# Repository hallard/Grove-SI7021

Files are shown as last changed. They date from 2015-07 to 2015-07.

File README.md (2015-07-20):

Grove SI7021 Temperature and Humidity Sensor
============================================

Boards made for testing and validate Ultra Low Power node boards you can connect grove connector to make it original "grove" or header pin to make it for breadboarding.

- The SI7021 pads have been resized to be easily hand soldered with an iron soldering.
- You can enable/disable the pullup with a solder pad.
- This board as no regulator on board, should be used only with 3.3V devices or add a level shifter.

##Detailed Description

Everything about ULPNode used with this board is located [here][1] on my blog

##Schematics
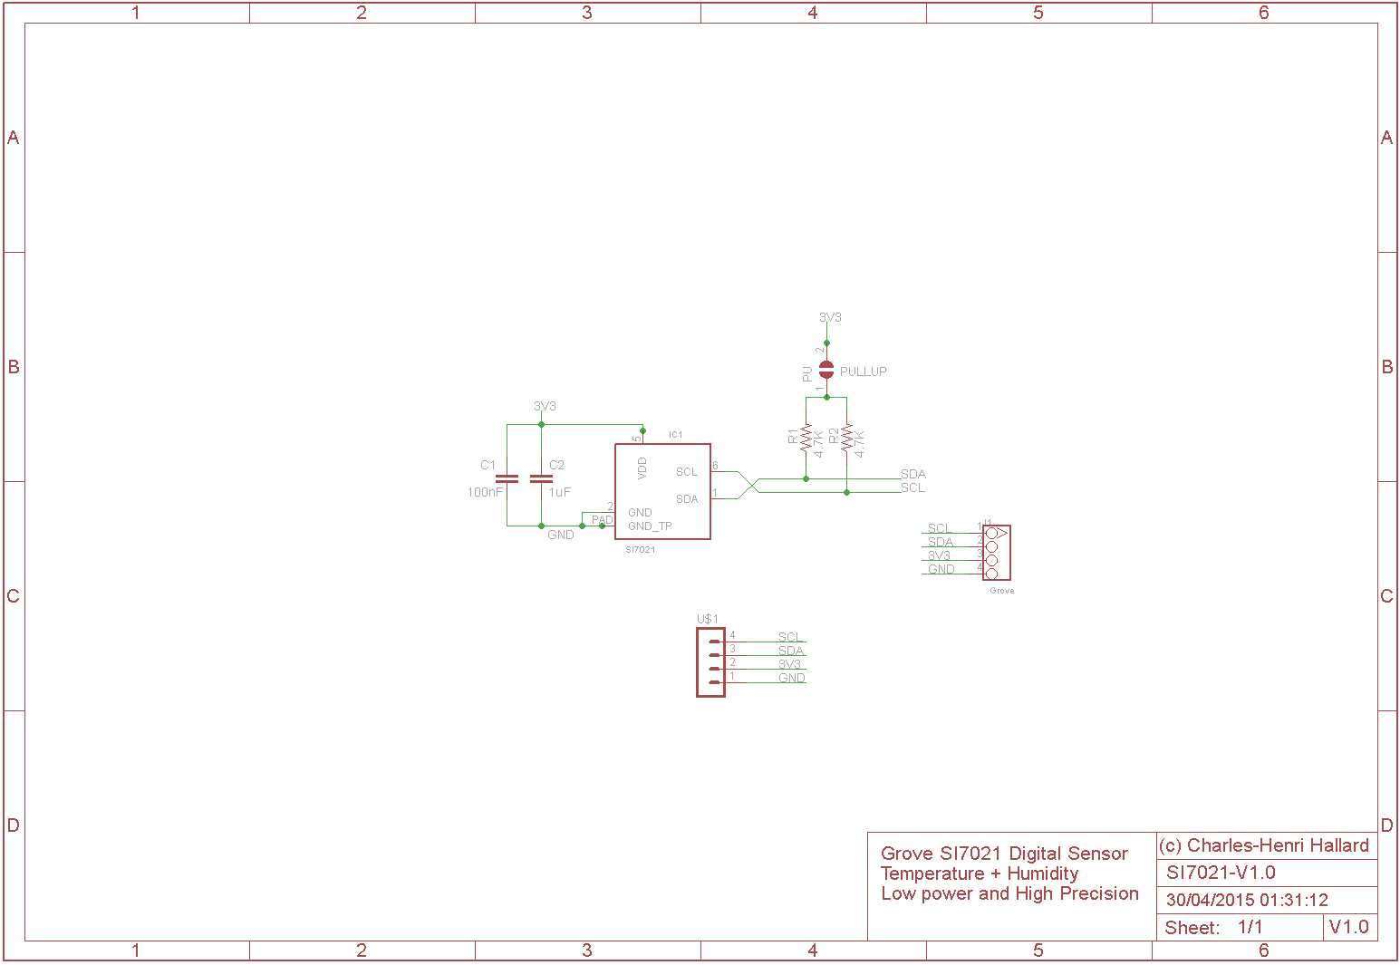
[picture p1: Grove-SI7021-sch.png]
schematics
  

##Boards  
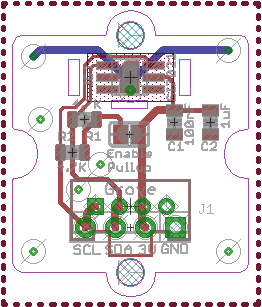
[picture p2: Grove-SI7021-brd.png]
board V1.0
&nbsp;
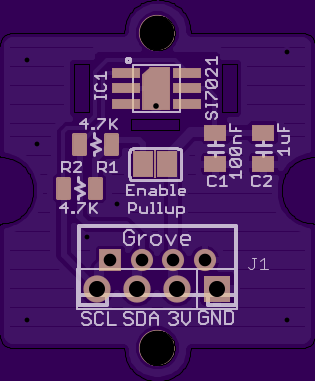
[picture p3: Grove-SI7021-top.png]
top V1.0
&nbsp;
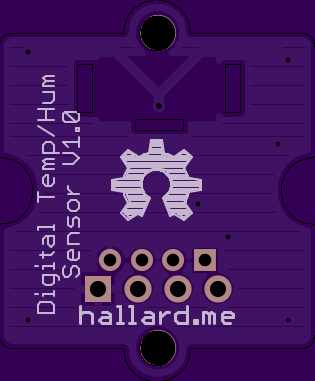
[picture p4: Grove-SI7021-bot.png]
bottom V1.0


You can order PCB directly from [OSHPark](https://oshpark.com/shared_projects/upb8JwuB)

##Library
There are lot of library to drive this one, the Sparkfun's [one][3] works fine

##Picture of assembled boards
Assembled boards

##Misc
See news and other projects on my [blog][2] 
 
[1]: https://hallard.me/category/ulpnode/
[2]: http://hallard.me
[3]: https://github.com/sparkfun/SparkFun_HTU21D_Breakout_Arduino_Library

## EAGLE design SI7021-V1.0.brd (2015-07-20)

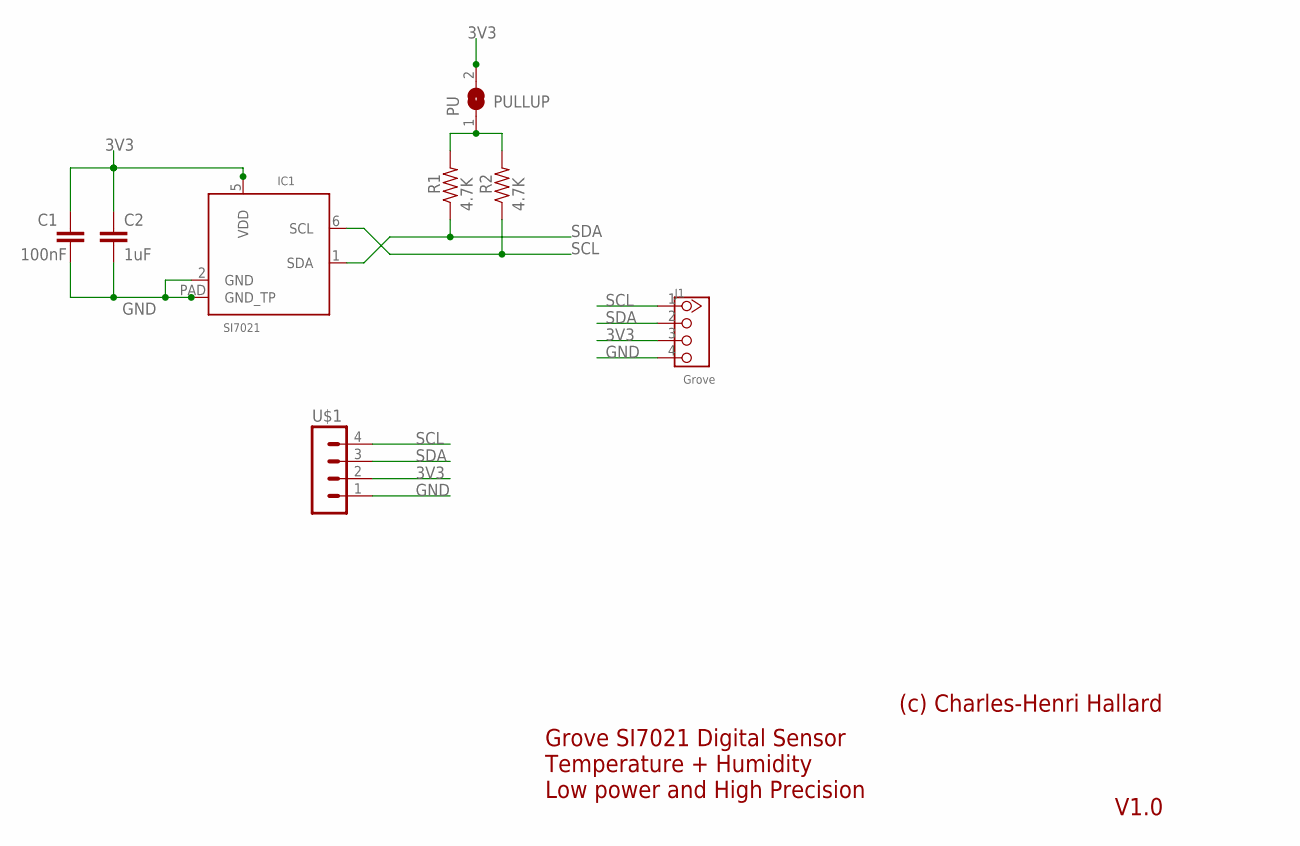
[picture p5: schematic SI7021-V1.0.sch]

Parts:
C1: 100nF; 0805-CAP
C2: 1uF; 0805-CAP
IC1: SI7021; DFN6-3X3-LONG
J1: Grove; 4P-2.0
PU: SOLDERJUMPERREFLOW_NOPASTE; SOLDERJUMPER_REFLOW_NOPASTE
R1, R2: 4.7K; 0805-RES
U$1: CON_HEADER_1X04'SMALL''; M1X4

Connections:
3V3: C1.1, C2.1, IC1.5 (VDD), J1.3, PU.2, U$1.2
GND: C1.2, C2.2, IC1.2 (GND), IC1.PAD (GND_TP), J1.4, U$1.1
PULLUP: PU.1, R1.2, R2.2
SCL: IC1.6 (SCL), J1.1, R2.1, U$1.4
SDA: IC1.1 (SDA), J1.2, R1.1, U$1.3

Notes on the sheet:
Grove SI7021 Digital Sensor Temperature + Humidity Low power and High Precision
(c) Charles-Henri Hallard
V1.0

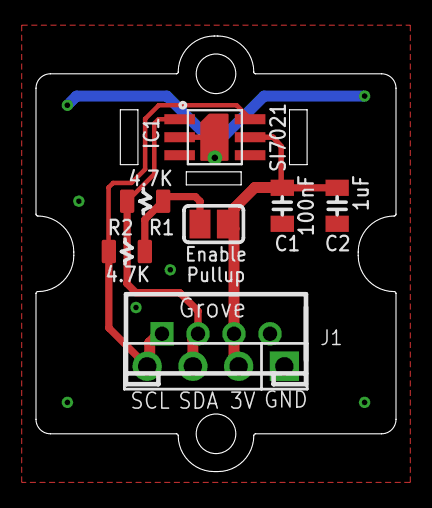
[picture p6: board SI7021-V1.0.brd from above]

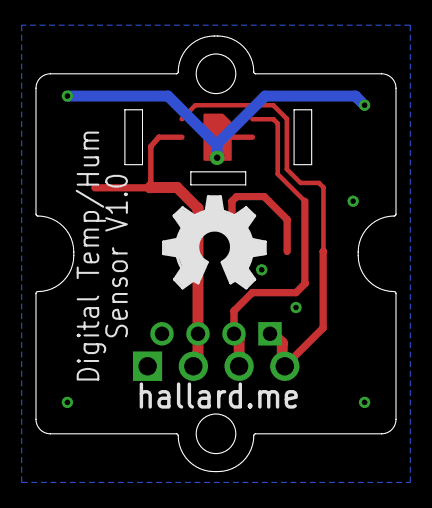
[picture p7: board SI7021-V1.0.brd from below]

Board: 2 copper layers, 20.0 x 24.2 mm, 10 parts (2 on the bottom side), 5 nets.

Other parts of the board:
U$2: 1U-DIM-W/-DRILL
U$4: OSHW_FILLX200_NOTEXT

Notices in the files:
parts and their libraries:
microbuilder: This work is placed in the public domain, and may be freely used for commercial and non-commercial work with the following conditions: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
